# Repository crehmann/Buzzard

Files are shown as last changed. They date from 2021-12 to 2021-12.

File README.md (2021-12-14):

# Buzzard

Buzzard is a 40 keys ergonomic split keyboard. The layout is inspired by the [Architeuthis dux](https://github.com/tapioki/cephalopoda/tree/main/Architeuthis%20dux) with pinky, ring, index, and inner columns splayed at 15, 5, 0, -5, -5 degrees. However, it as two additional pinky keys and a modified thumb cluster.

## Features

- Integrated TrackPoint reset circuit and two possible positions to mount a TrackPoint to the bottom of the PCB. Either between the two inner columns or between the index and middle finger columns
- Mounting option for a linear actuator ([HapticBuzz from pimoroni](https://shop.pimoroni.com/products/drv2605l-linear-actuator-haptic-breakout))
- I2C interface for an OLED display
- Wireless Ready (however, without TrackPoint / linear actuator support):
  - Battery switch / connector
  - Option to use a battery friendly Sharp memory display instead of an OLED display
- Choc-spaced
- Partially hot swap sockets supported (not around the TrackPoint  module)
- Either surface mount or through hole components can be used

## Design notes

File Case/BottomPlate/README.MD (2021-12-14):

# Top Plate

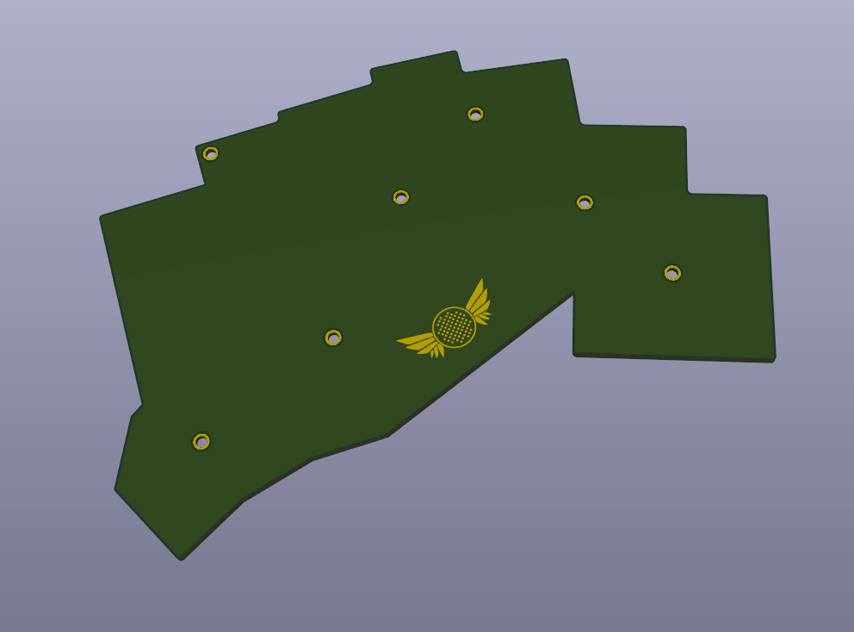
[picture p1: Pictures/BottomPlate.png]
Render Image


**Note:** The top and bottom plate are a little bit larger design than the keyboard PCB itself. I am planning to also create a 3d printed border that can be clamped between the top and bottom plate.

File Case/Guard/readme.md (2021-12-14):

**Note:** I have not tested the guard with a laser cutter service or similar. I cut it by hand which is a lot less precise and I don't know if the dimensions are correct when using a laser cutter (service)

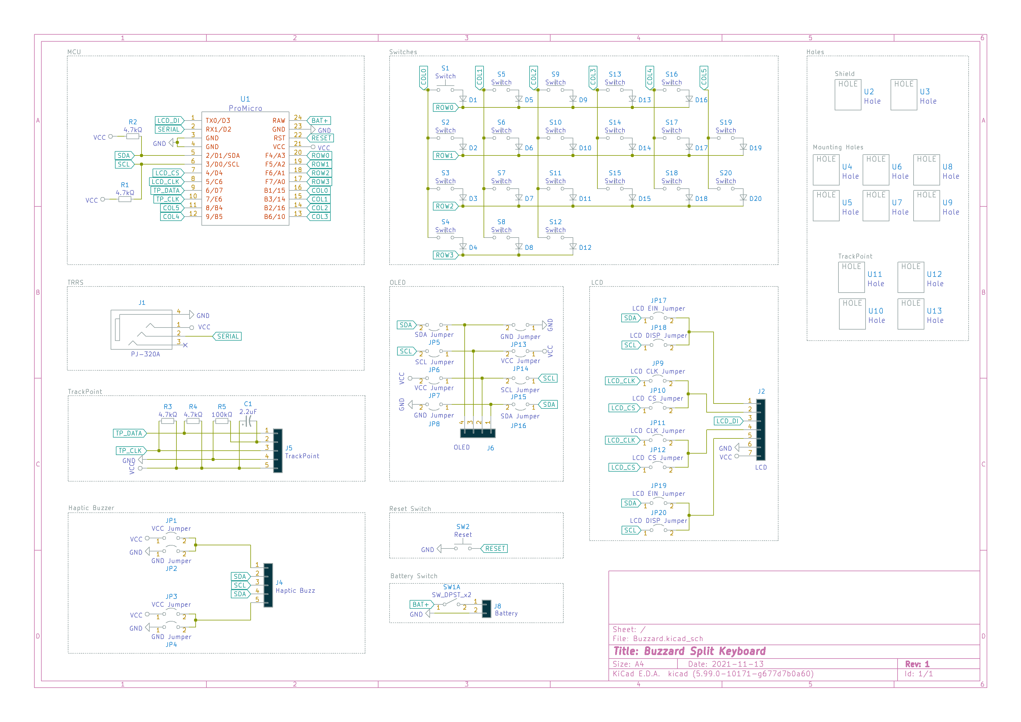
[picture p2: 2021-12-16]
Pictures/schematics.png

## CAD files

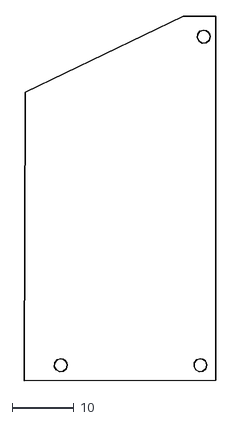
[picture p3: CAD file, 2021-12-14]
Case/Guard/guard.dxf
30.9 x 58.7

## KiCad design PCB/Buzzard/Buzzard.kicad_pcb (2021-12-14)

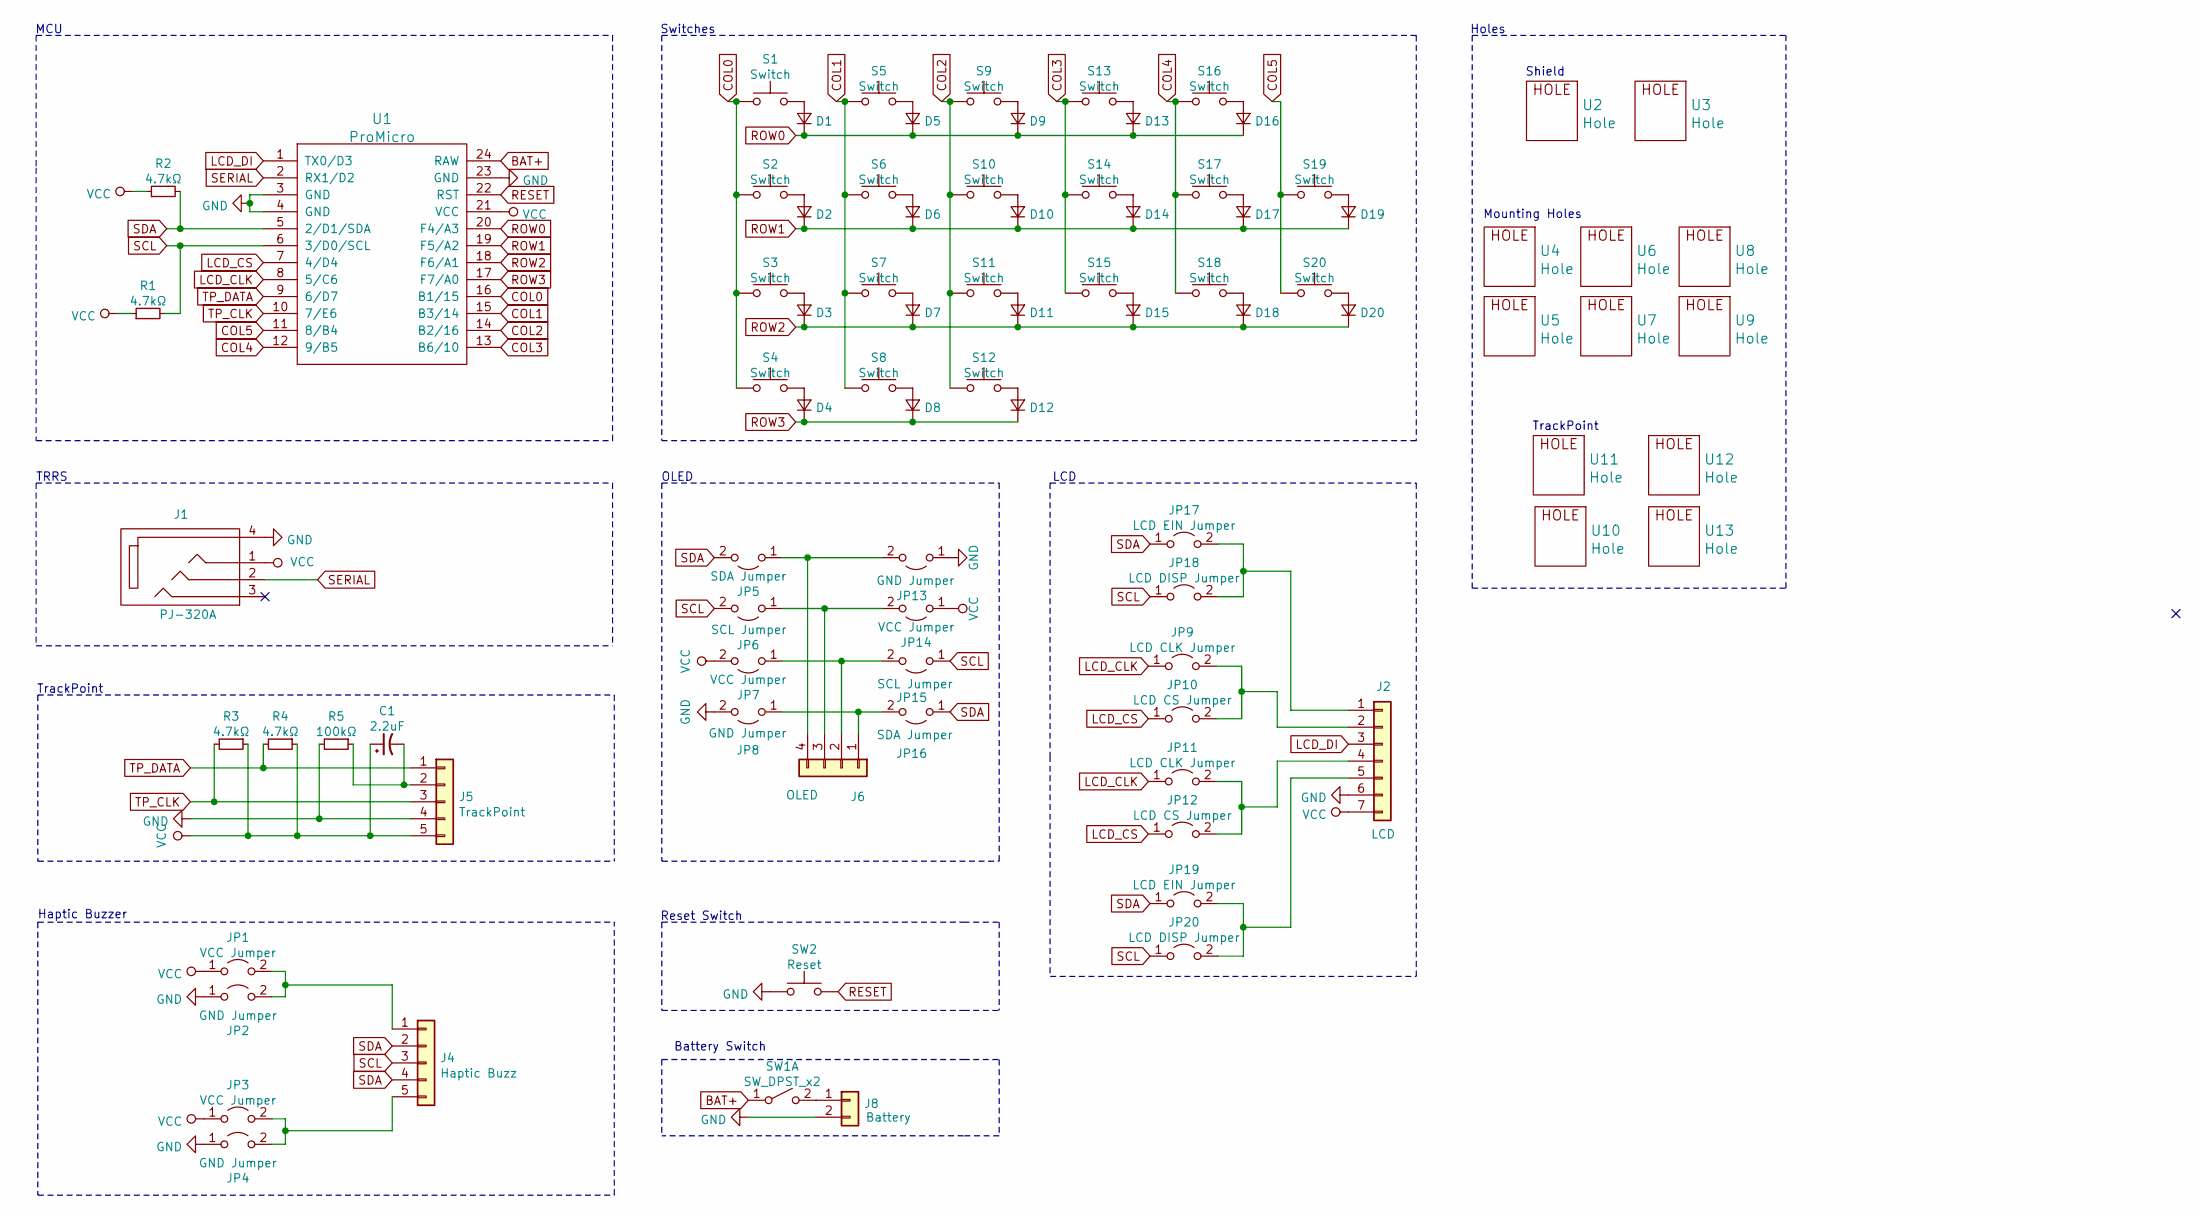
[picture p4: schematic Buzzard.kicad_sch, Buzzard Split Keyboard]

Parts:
C1: 2.2uF; C_THT_SMD_0805_HandSolder_Reversable
D1, D2, D3, D4, D5, D6, D7, D8, D9, D10, D11, D12, D13, D14, D15, D16, D17, D18, D19, D20: D_Small; D3_TH_SMD_v2
J1: PJ-320A; MJ-4PP-9
J2: LCD; SharpMemoryLcdBreakout-Reversable
J4: Haptic Buzz; Pimoroni Haptic Buzz DRV2605L Driver
J5: TrackPoint; PinHeader_1x05_P2.54mm_Vertical
J6: OLED
J8: Battery; JST_PH_S2B-PH-K_1x02_P2.00mm_Horizontal
JP1, JP3, JP7, JP14: VCC Jumper; SolderJumper-2_P1.3mm_Open_Pad1.0x1.5mm
JP2, JP4, JP8, JP13: GND Jumper; SolderJumper-2_P1.3mm_Open_Pad1.0x1.5mm
JP5, JP16: SDA Jumper; SolderJumper-2_P1.3mm_Open_Pad1.0x1.5mm
JP6, JP15: SCL Jumper; SolderJumper-2_P1.3mm_Open_Pad1.0x1.5mm
JP9, JP11: LCD CLK Jumper; SolderJumper-2_P1.3mm_Open_Pad1.0x1.5mm
JP10, JP12: LCD CS Jumper; SolderJumper-2_P1.3mm_Open_Pad1.0x1.5mm
JP17, JP19: LCD EIN Jumper; SolderJumper-2_P1.3mm_Open_Pad1.0x1.5mm
JP18, JP20: LCD DISP Jumper; SolderJumper-2_P1.3mm_Open_Pad1.0x1.5mm
R1, R2, R3, R4: 4.7kΩ; Resistor-TH_SMD
R5: 100kΩ; Resistor-TH_SMD
S1, S5, S6, S9, S10: Switch; SW_PG1350_reversible
S2, S3, S4, S7, S8, S11, S12, S13, S14, S15, S16, S17, S18, S19, S20: Switch; Kailh_socket_PG1350_optional_reversible.kicad_mod
SW1: SW_DPST_x2; SW-TH_3P-L9.1-W3.5-P2.50-S3.20-A3
SW2: Reset; SW_Tactile_SPST_Angled_PTS645Vx39-2LFS
U1: ProMicro; ProMicro_v2
U2, U3: Hole; M2_HOLE_PCB
U4, U5, U6, U7, U8, U9, U10, U11, U12, U13: Hole; HOLE_M2_TH

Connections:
BAT+: SW1.1 (A), U1.24 (RAW)
COL0: S1.1, S2.1, S3.1, S4.1, U1.16 (B1/15)
COL1: S5.1, S6.1, S7.1, S8.1, U1.15 (B3/14)
COL2: S9.1, S10.1, S11.1, S12.1, U1.14 (B2/16)
COL3: S13.1, S14.1, S15.1, U1.13 (B6/10)
COL4: S16.1, S17.1, S18.1, U1.12 (9/B5)
COL5: S19.1, S20.1, U1.11 (8/B4)
GND: J1.4, J2.6, J5.4, J8.2, JP2.1 (A), JP4.1 (A), JP8.2 (B), JP13.1 (A), R5.2, SW2.1, U1.3 (GND), U1.4 (GND), U1.23 (GND)
LCD_CLK: JP9.1 (A), JP11.1 (A), U1.8 (5/C6)
LCD_CS: JP10.1 (A), JP12.1 (A), U1.7 (4/D4)
LCD_DI: J2.3, U1.1 (TX0/D3)
unnamed: C1.2, J5.2, R5.1
unnamed: D1.2 (A), S1.2
unnamed: D2.2 (A), S2.2
unnamed: D3.2 (A), S3.2
unnamed: D4.2 (A), S4.2
unnamed: D5.2 (A), S5.2
unnamed: D6.2 (A), S6.2
unnamed: D7.2 (A), S7.2
unnamed: D8.2 (A), S8.2
unnamed: D9.2 (A), S9.2
unnamed: D10.2 (A), S10.2
unnamed: D11.2 (A), S11.2
unnamed: D12.2 (A), S12.2
unnamed: D13.2 (A), S13.2
unnamed: D14.2 (A), S14.2
unnamed: D15.2 (A), S15.2
unnamed: D16.2 (A), S16.2
unnamed: D17.2 (A), S17.2
unnamed: D18.2 (A), S18.2
unnamed: D19.2 (A), S19.2
unnamed: D20.2 (A), S20.2
unnamed: J2.1, JP17.2 (B), JP18.2 (B)
unnamed: J2.2, JP9.2 (B), JP10.2 (B)
unnamed: J2.4, JP11.2 (B), JP12.2 (B)
unnamed: J2.5, JP19.2 (B), JP20.2 (B)
unnamed: J4.1, JP1.2 (B), JP2.2 (B)
unnamed: J4.5, JP3.2 (B), JP4.2 (B)
unnamed: J6.1, JP8.1 (A), JP16.2 (B)
unnamed: J6.2, JP7.1 (A), JP15.2 (B)
unnamed: J6.3, JP6.1 (A), JP14.2 (B)
unnamed: J6.4, JP5.1 (A), JP13.2 (B)
unnamed: J8.1, SW1.2 (B)
RESET: SW2.2, U1.22 (RST)
ROW0: D1.1 (K), D5.1 (K), D9.1 (K), D13.1 (K), D16.1 (K), U1.20 (F4/A3)
ROW1: D2.1 (K), D6.1 (K), D10.1 (K), D14.1 (K), D17.1 (K), D19.1 (K), U1.19 (F5/A2)
ROW2: D3.1 (K), D7.1 (K), D11.1 (K), D15.1 (K), D18.1 (K), D20.1 (K), U1.18 (F6/A1)
ROW3: D4.1 (K), D8.1 (K), D12.1 (K), U1.17 (F7/A0)
SCL: J4.3, JP6.2 (B), JP15.1 (A), JP18.1 (A), JP20.1 (A), R1.2, U1.6 (3/D0/SCL)
SDA: J4.2, J4.4, JP5.2 (B), JP16.1 (A), JP17.1 (A), JP19.1 (A), R2.2, U1.5 (2/D1/SDA)
SERIAL: J1.2, U1.2 (RX1/D2)
TP_CLK: J5.3, R3.2, U1.10 (7/E6)
TP_DATA: J5.1, R4.2, U1.9 (6/D7)
VCC: C1.1, J1.1, J2.7, J5.5, JP1.1 (A), JP3.1 (A), JP7.2 (B), JP14.1 (A), R1.1, R2.1, R3.1, R4.1, U1.21 (VCC)

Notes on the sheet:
MCU
TRRS
TrackPoint
Haptic Buzzer
OLED
Switches
Reset Switch
Battery Switch
LCD
Holes
Shield
Mounting Holes

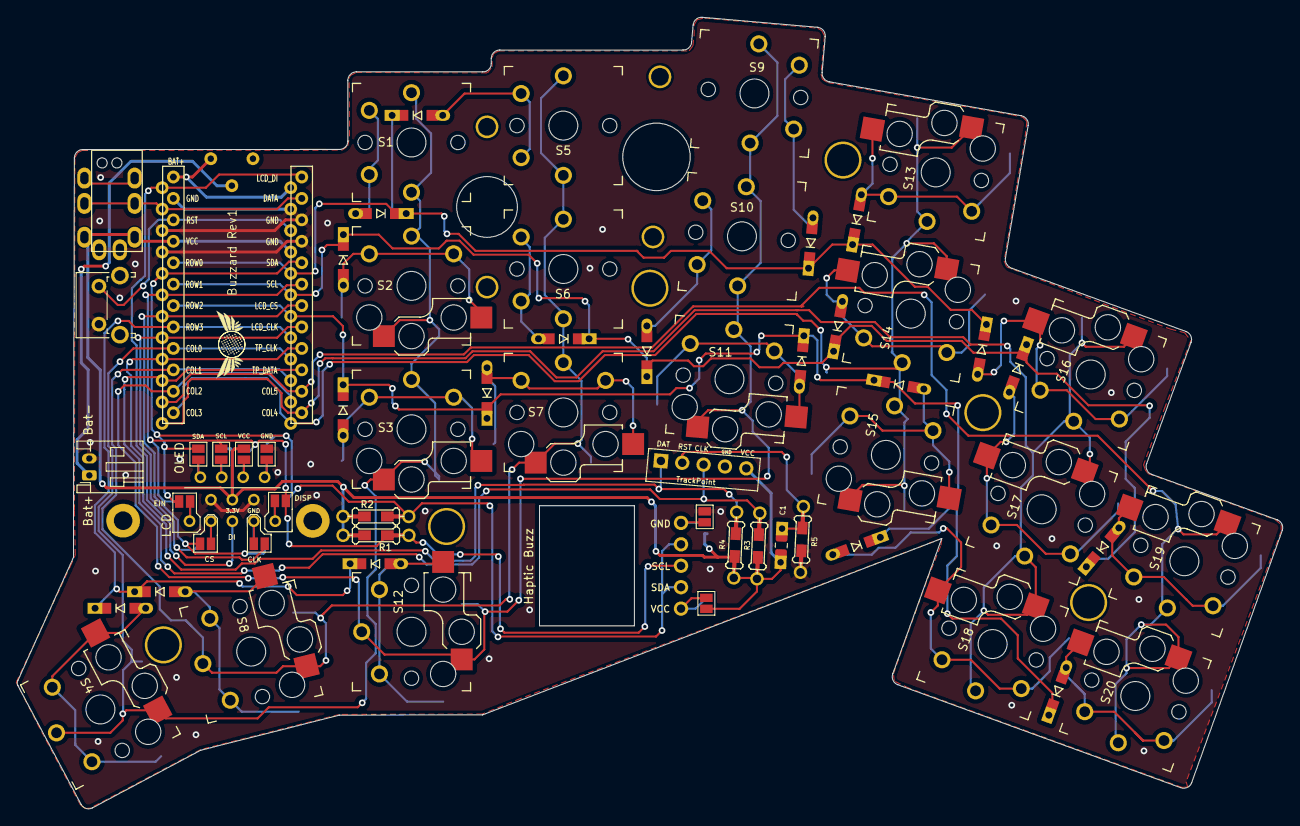
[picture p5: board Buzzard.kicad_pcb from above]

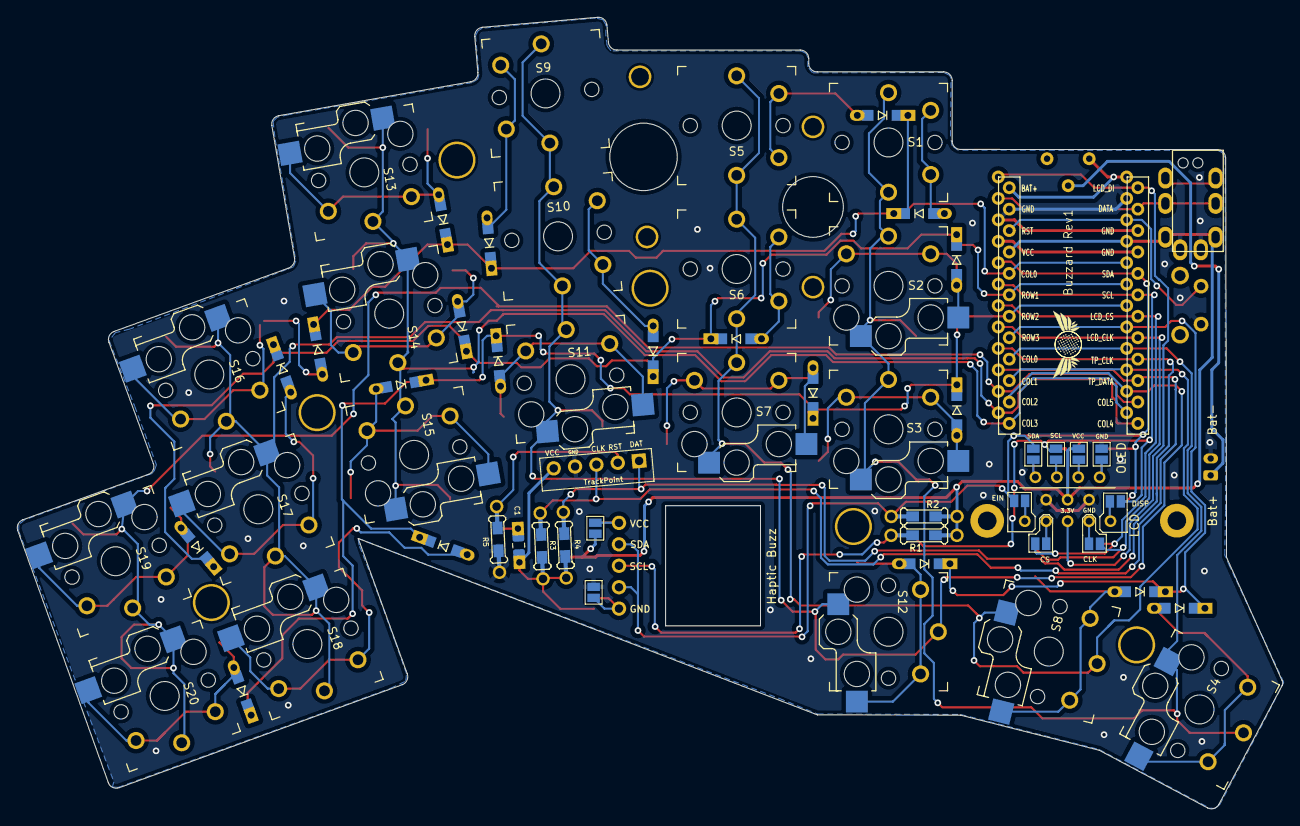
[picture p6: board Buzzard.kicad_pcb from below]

Board: 2 copper layers, 150.0 x 93.8 mm, 87 parts (11 on the bottom side), 54 nets.

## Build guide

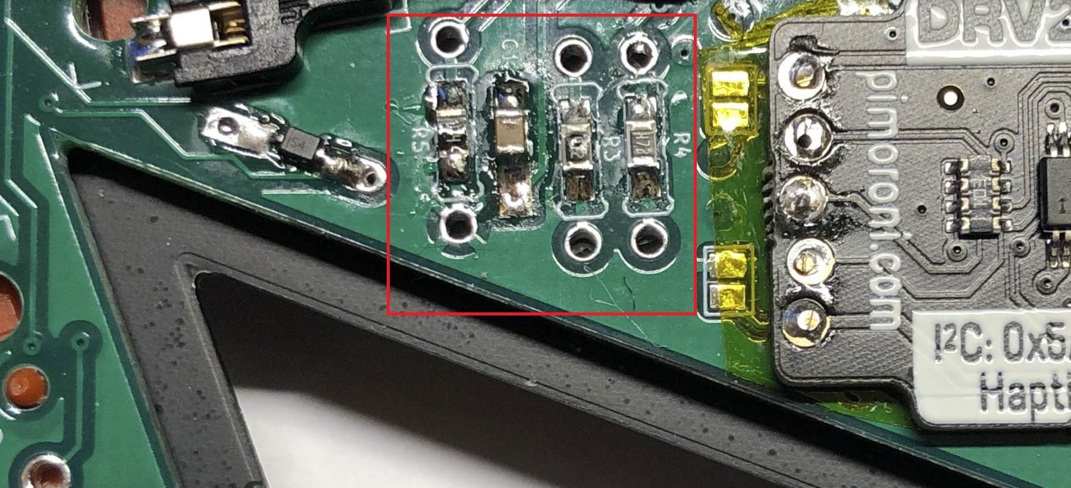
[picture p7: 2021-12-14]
Pictures/build_guide_trackpoint_reset.jpg

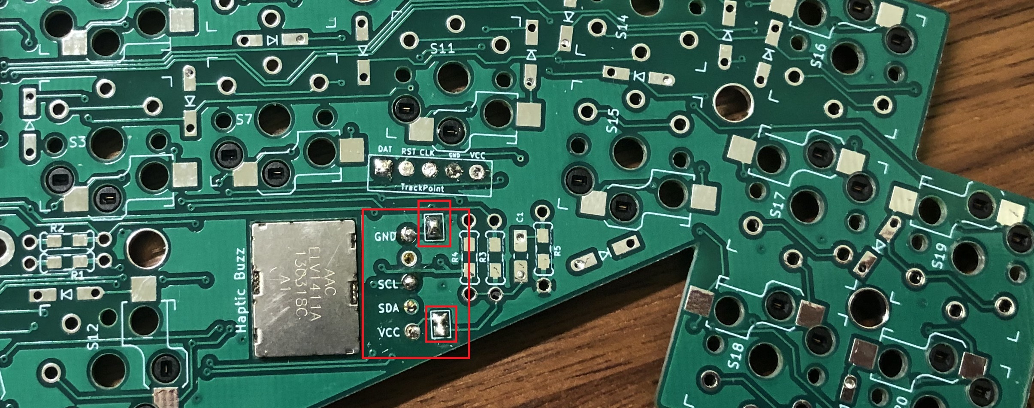
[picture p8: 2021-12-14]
Pictures/build_guide_haptic_buzz.jpg

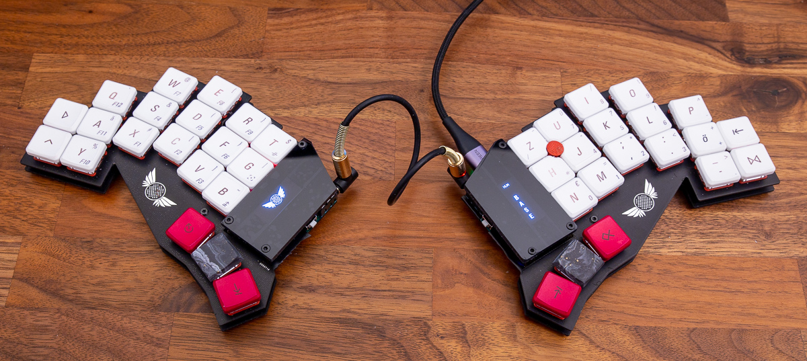
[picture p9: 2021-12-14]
Pictures/build_guide_final.jpg

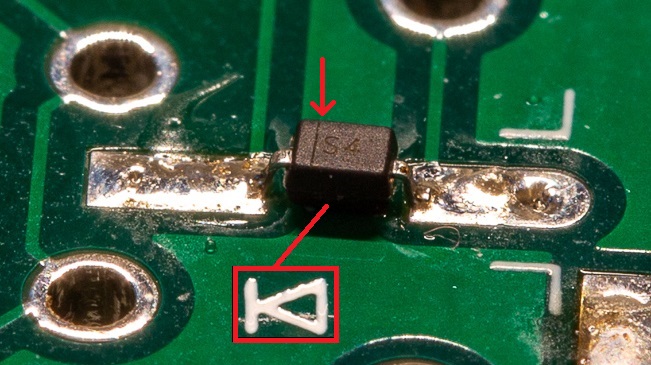
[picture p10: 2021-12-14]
Pictures/build_guide_diode_smd.jpg

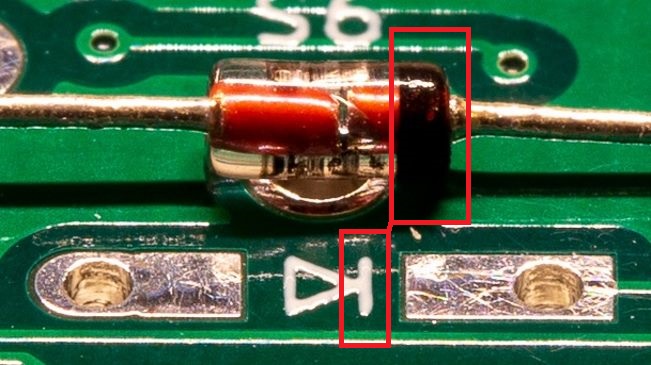
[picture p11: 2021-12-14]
Pictures/build_guide_diode_tht.jpg

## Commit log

2021-10-25 add schematics and footprints
    [Buzzard.kicad_pcb, Buzzard.kicad_sch]
2021-10-26 started with pcb design and placed switches
    [Buzzard.kicad_pcb, Buzzard.kicad_sch]
2021-10-27 further work on pcb
    [Buzzard.kicad_pcb, Buzzard.kicad_sch]
2021-10-29 further work on the pcb
    [Buzzard.kicad_pcb, Buzzard.kicad_sch]
2021-10-29 further work
    [Buzzard.kicad_pcb, Buzzard.kicad_sch]
2021-10-31 replaced trrs symbol and fixed connections
    [Buzzard.kicad_pcb, Buzzard.kicad_sch]
2021-10-31 replaced lcd footprint and fixed connections
    [Buzzard.kicad_pcb, Buzzard.kicad_sch]
2021-10-31 placement of trackpoint circuit and thumb cluster
    [Buzzard.kicad_pcb]
2021-11-01 added mounting holes
    [Buzzard.kicad_pcb, Buzzard.kicad_sch]
2021-11-01 diode placement
    [Buzzard.kicad_pcb, Buzzard.kicad_sch]
2021-11-03 moved mcu and some rework
    moved mcu more to the left
    [Buzzard.kicad_pcb]
2021-11-03 wiring of switches
    [Buzzard.kicad_pcb]
2021-11-03 rounded edge cuts
    [Buzzard.kicad_pcb, Buzzard.kicad_sch]
2021-11-03 work on silk screen
    [Buzzard.kicad_pcb]
2021-11-03 fix errors and warnings
    [Buzzard.kicad_pcb]
2021-11-03 moved pinky column more to the middle
    [Buzzard.kicad_pcb]
2021-11-03 adding logo
    [Buzzard.kicad_pcb]
2021-11-03 added topplate
    [TopPlate.kicad_pcb]
2021-11-04 add logo and better through holes
    [TopPlate.kicad_pcb]
2021-11-10 switched trrs lines and TP clock/data lines
    [Buzzard.kicad_pcb, Buzzard.kicad_sch]
2021-11-14 Some fine tuning and silkmask improvments
    [Buzzard.kicad_pcb, Buzzard.kicad_sch, TopPlate.kicad_pcb]
2021-12-04 add case render images
2021-12-04 add kicad files for bottom plate
    [BottomPlate.kicad_pcb]
2021-12-04 add readme for top and bottom plate
    [TopPlate.kicad_pcb]
2021-12-11 added guard
    [guard.dxf]
2021-12-16 add image of schematic
